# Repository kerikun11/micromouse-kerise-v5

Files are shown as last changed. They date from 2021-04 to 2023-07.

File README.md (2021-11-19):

# MicroMouse KERISE v5

ハーフサイズマイクロマウス

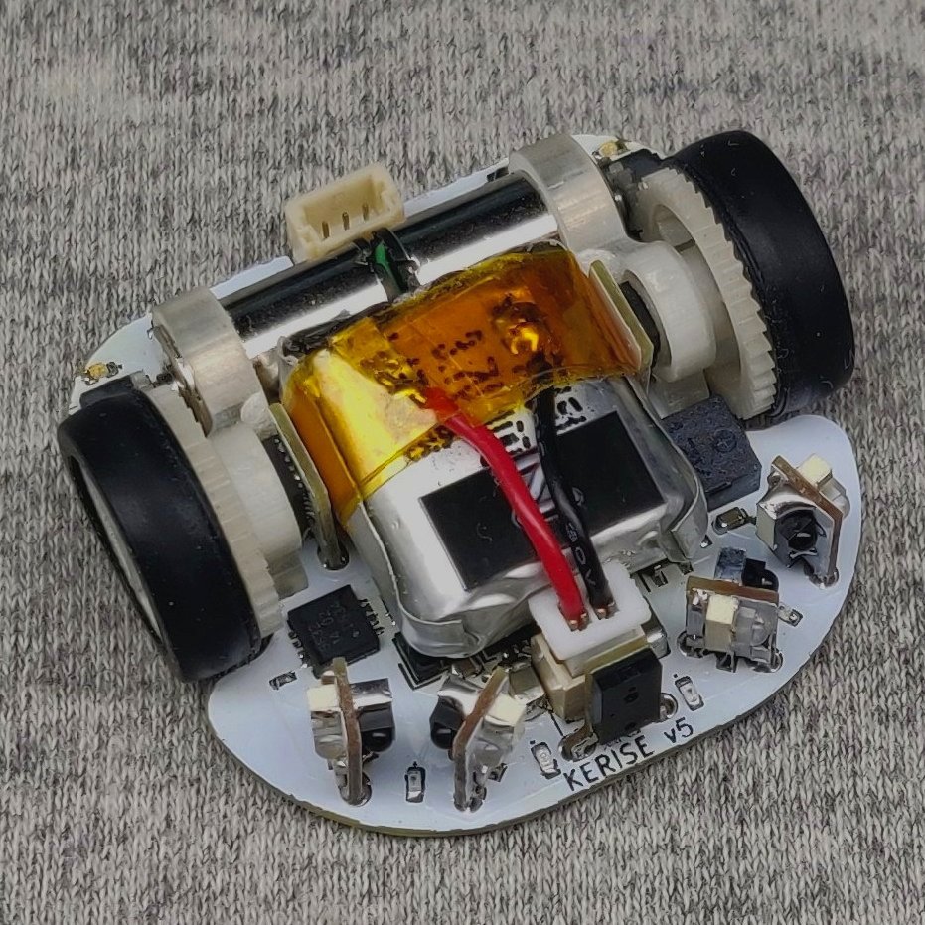
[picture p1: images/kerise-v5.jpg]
KERISE v5


## 戦績

なし

## スペック

| 部品 | 型番 | 備考 |
| :--- | :--- | :--- |
| モーター | 不明 | 直径6mm 長さ10mm コアレスモーター |
| エンコーダ | MA730 | 4096パルス 磁気式 |
| マイコン | ESP32-PICO-D4 | 240MHz dual core |
| 赤外線LED | SFH4045N | 波長940mm |
| フォトトランジスタ | SFH3015FA | 波長940nm |
| モータードライバ | DRV8835 | 最大電流1.5A x 2ch |
| 6軸センサ | ICM-20602 | 3軸ジャイロ+3軸加速度 |
| バッテリー | 不明 | 3.7V 25C 100mAh 1S |

## 回路設計

- KiCad

## 機体設計

- Fusion 360

## 開発環境

- PlatformIO Espressif32 Arduino

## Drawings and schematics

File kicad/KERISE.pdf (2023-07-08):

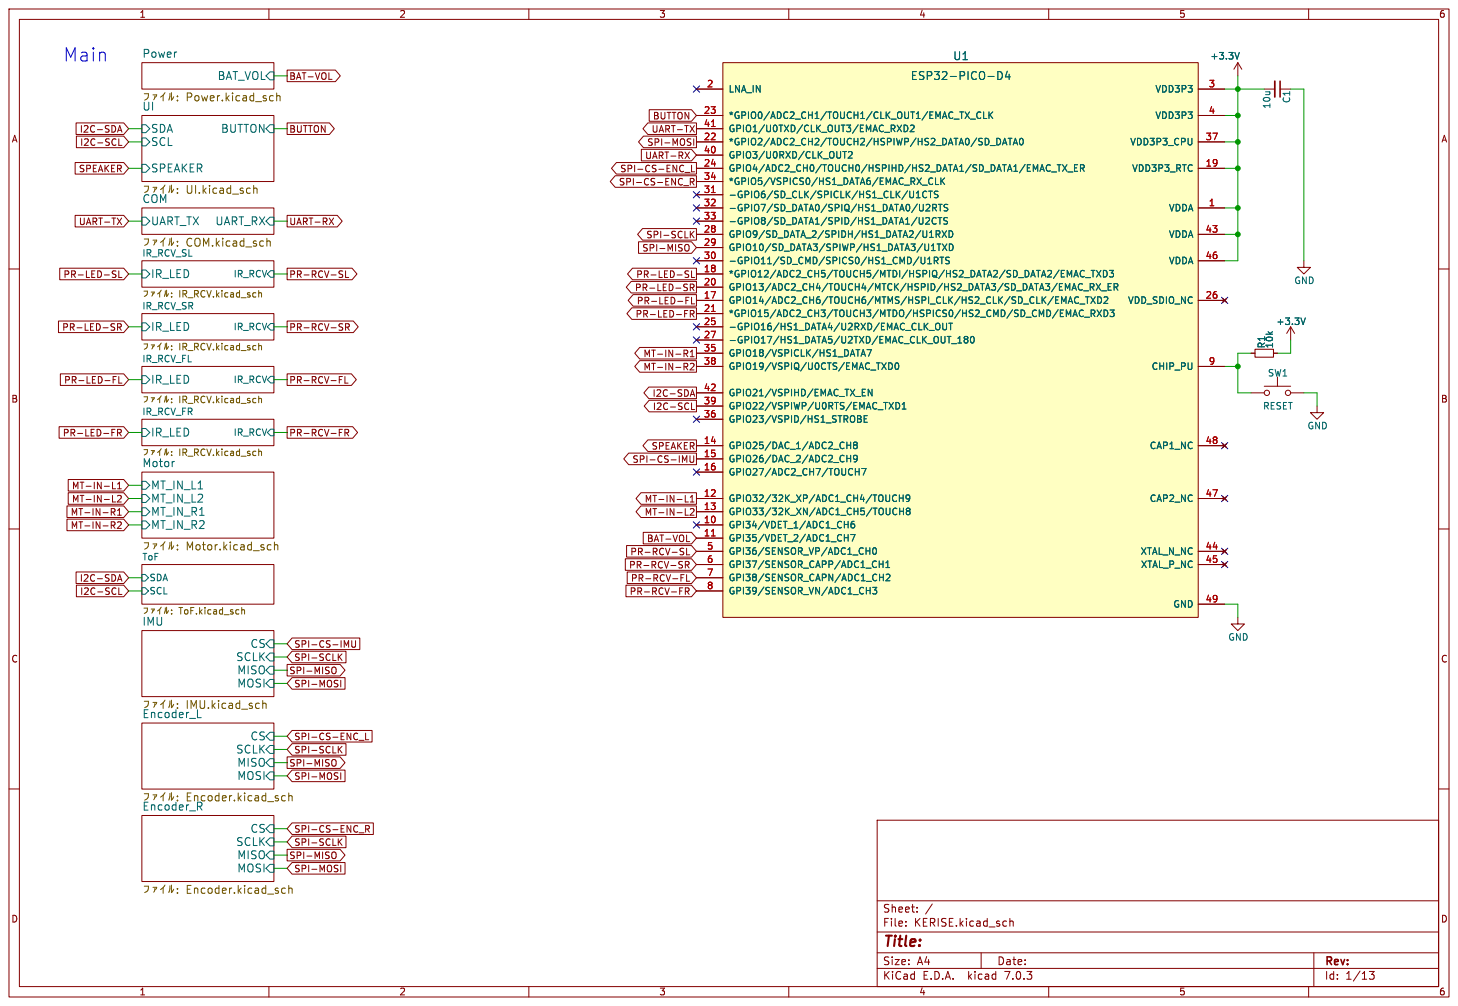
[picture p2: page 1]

BUTTON
PR-RCV-FL UART-RX

SPI-CS-ENC_L BUTTON
SPI-MOSI UART-TX

*GPIO2/ADC2_CH2/TOUCH2/HSPIWP/HS2_DATA0/SD_DATA0 22
I2C-SCL PR-LED-SL SPI-SCLK
SPI-MISO

PR-LED-FL PR-LED-SR

I2C-SDA MT-IN-R1 MT-IN-R2

SPI-MOSI SPI-CS-ENC_R

Id: 1/13 Title: File: KERISE.kicad_sch Sheet: /

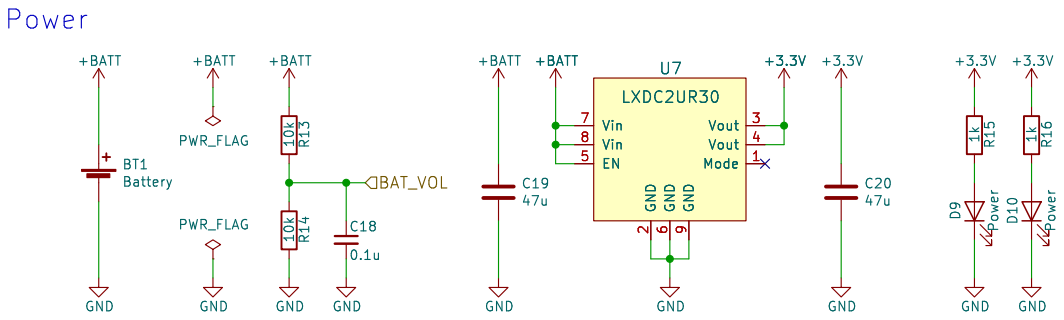
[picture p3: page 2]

2 Vout 3 Vout 4 EN 5 GND

Id: 2/13 Title: File: Power.kicad_sch Sheet: /Power/ C20

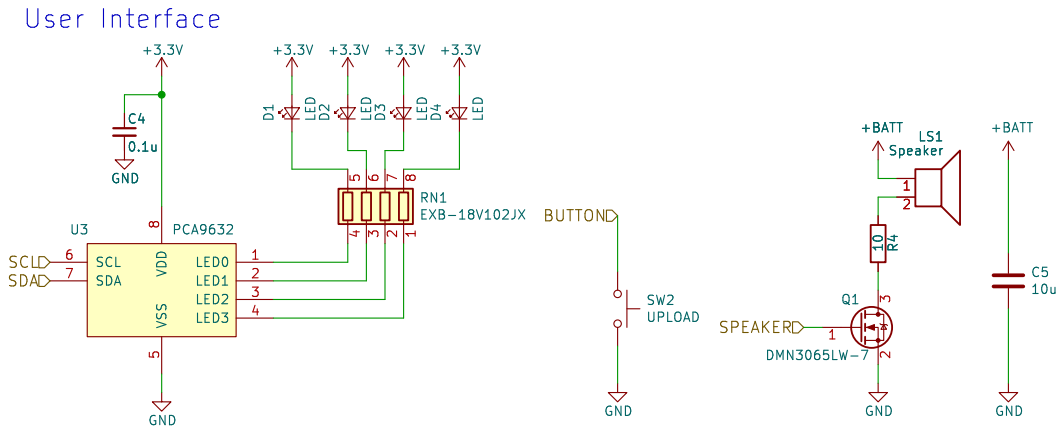
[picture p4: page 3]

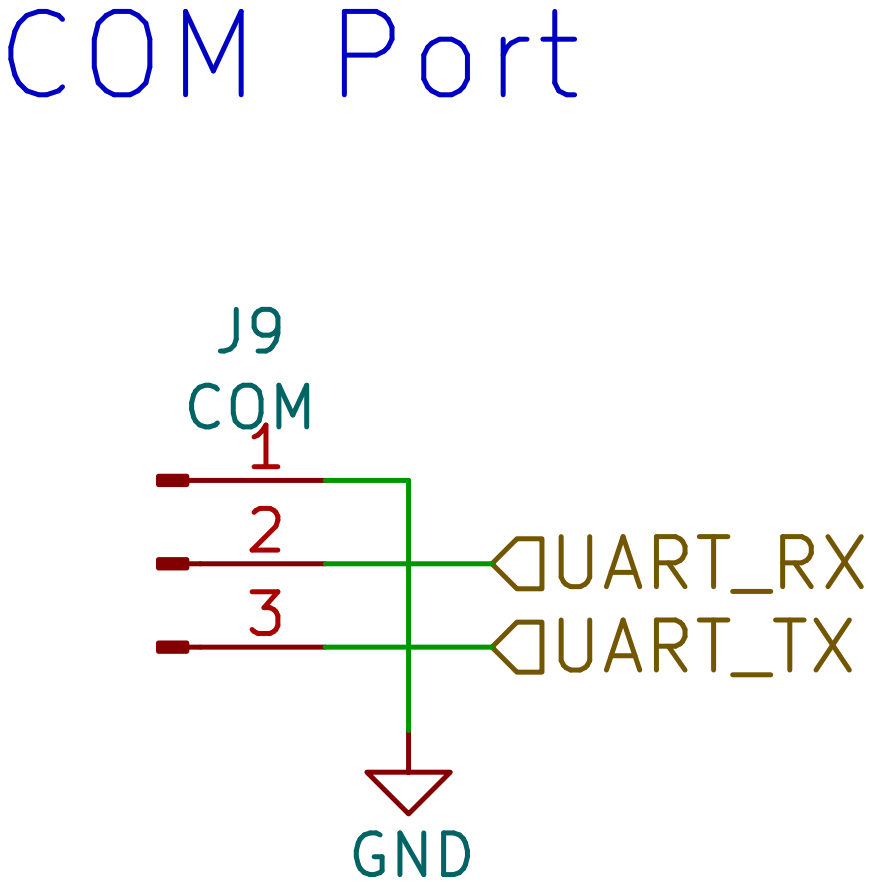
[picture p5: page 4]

Id: 4/13 Title: File: COM.kicad_sch Sheet: /COM/ GND

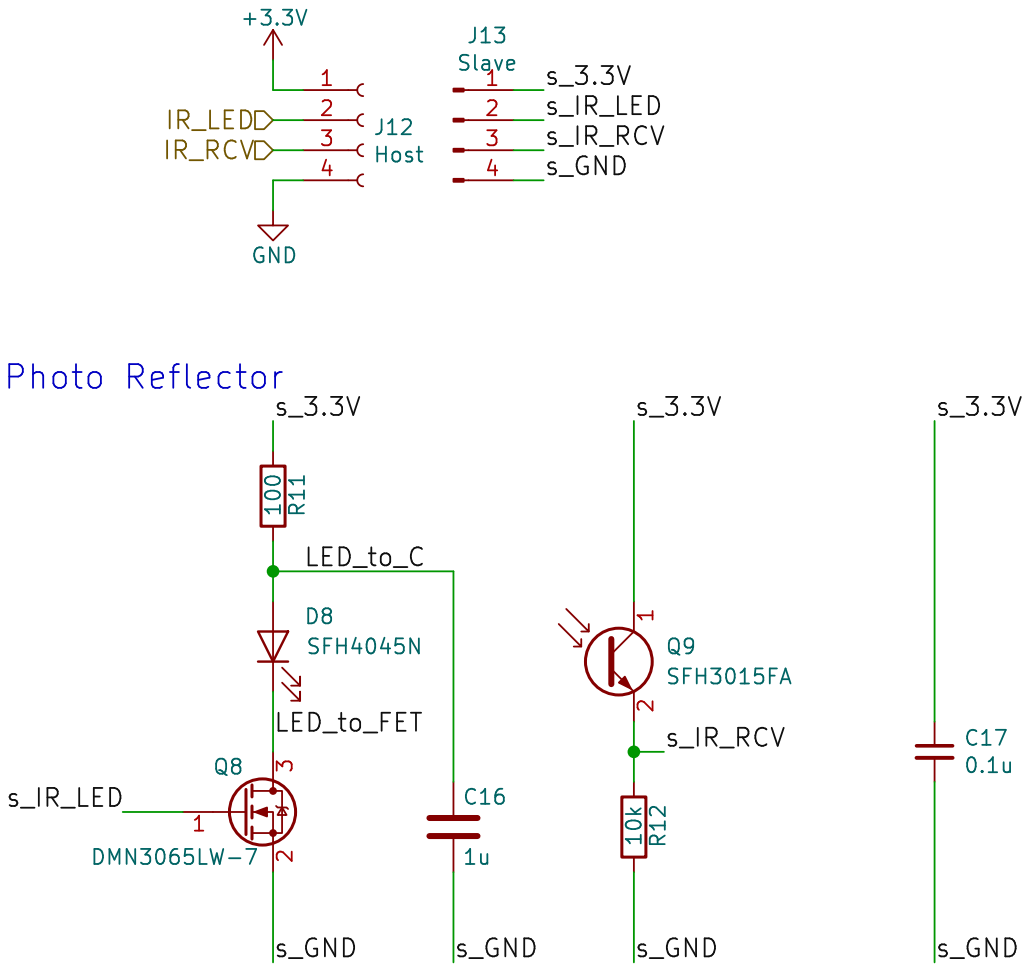
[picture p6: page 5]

Id: 5/13 Title: File: IR_RCV.kicad_sch Sheet: /IR_RCV_SL/ C17

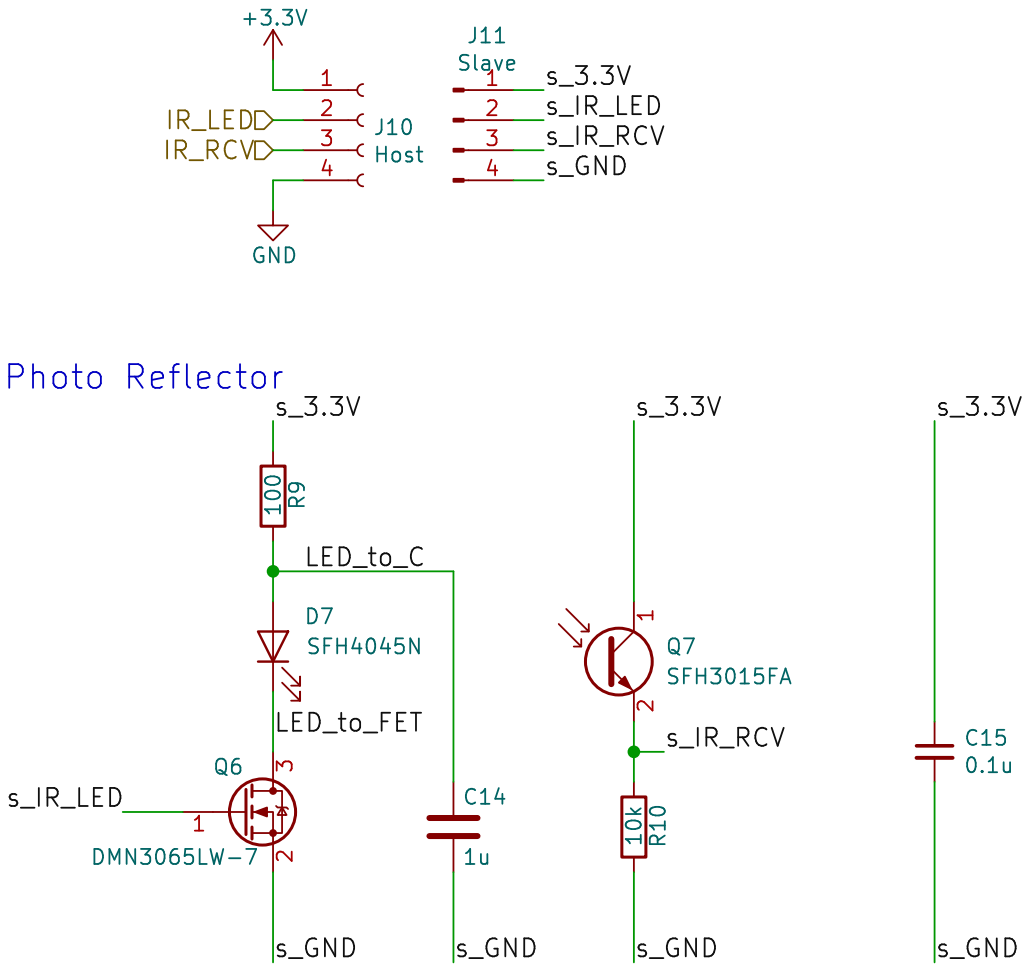
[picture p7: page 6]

Id: 6/13 Title: File: IR_RCV.kicad_sch Sheet: /IR_RCV_SR/ C15

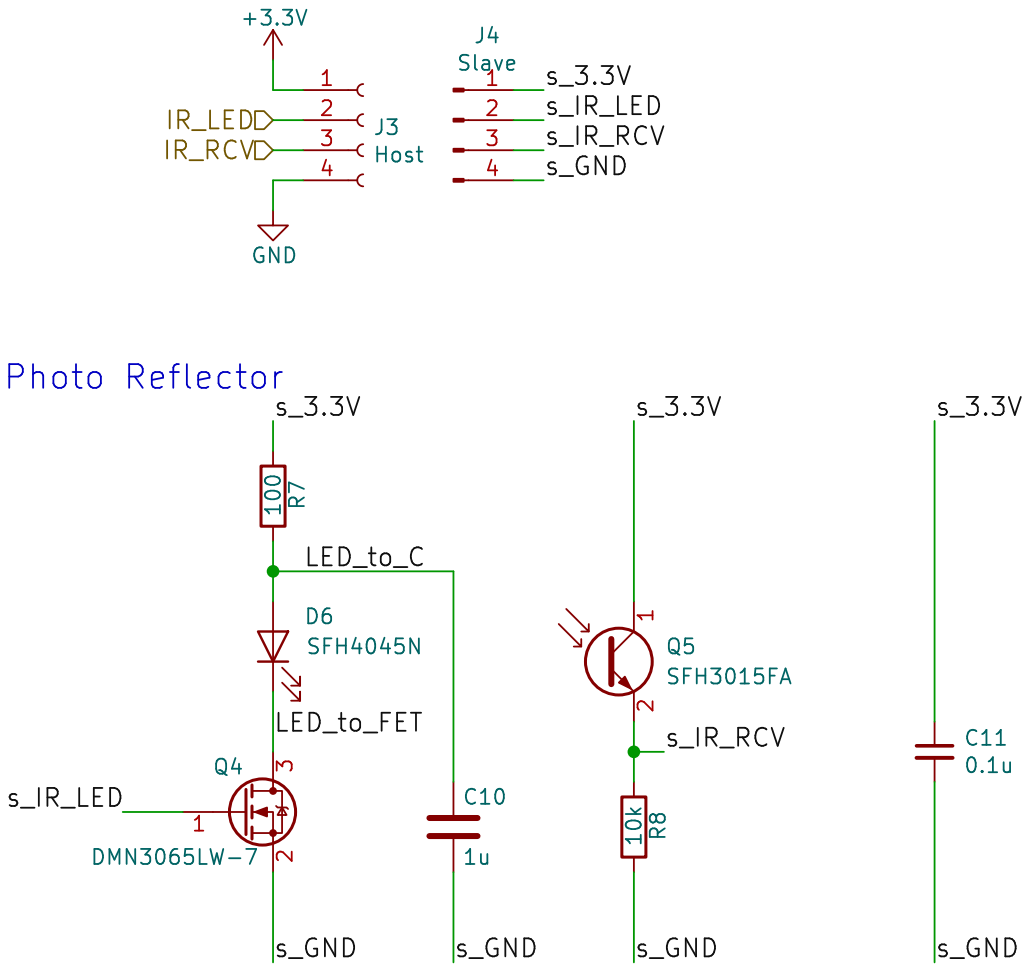
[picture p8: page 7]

Id: 7/13 Title: File: IR_RCV.kicad_sch Sheet: /IR_RCV_FL/ C11

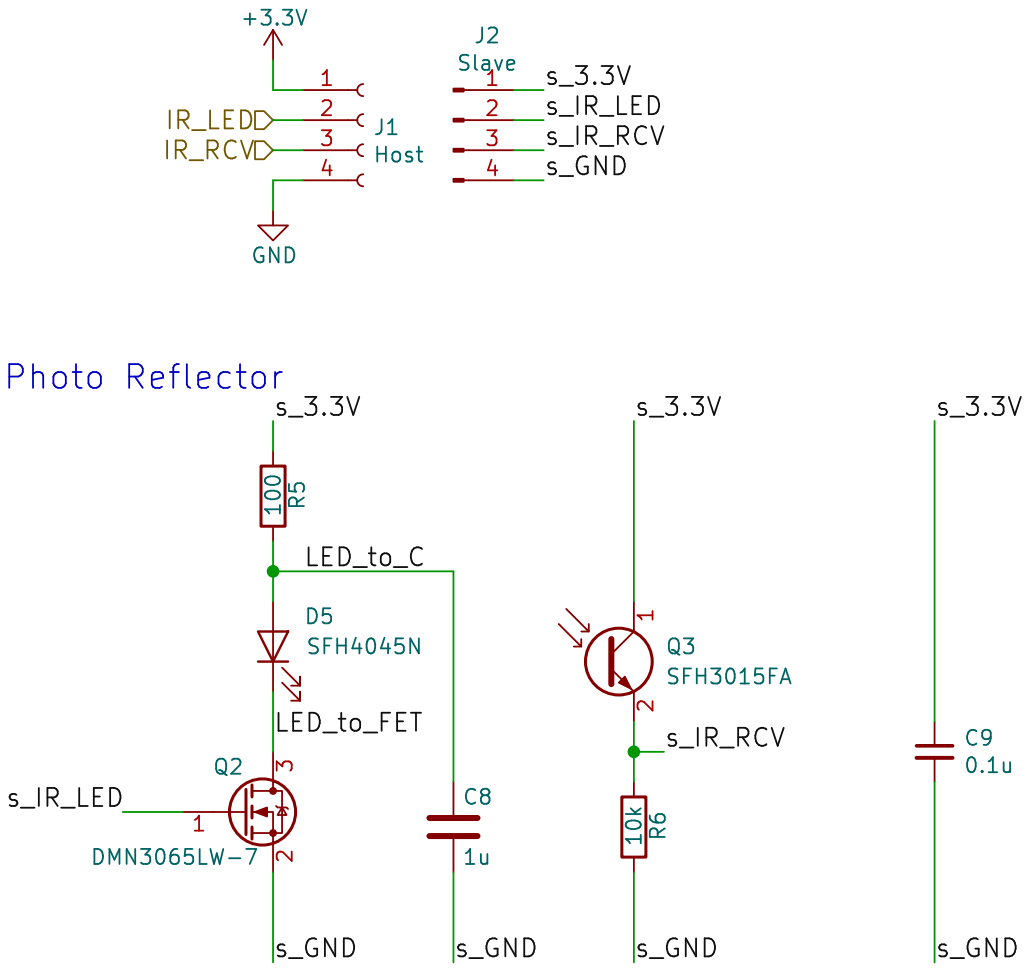
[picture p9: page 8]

Id: 8/13 Title: File: IR_RCV.kicad_sch Sheet: /IR_RCV_FR/ C9

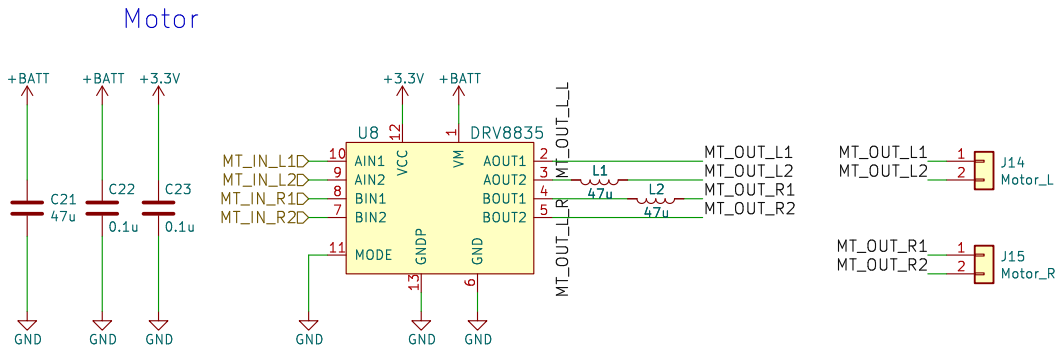
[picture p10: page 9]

1 AIN1 10 MODE 11 VCC 12 GNDP 13 AOUT1 2 AOUT2 3 BOUT1 4 BOUT2 5 GND

Id: 9/13 Title: File: Motor.kicad_sch Sheet: /Motor/

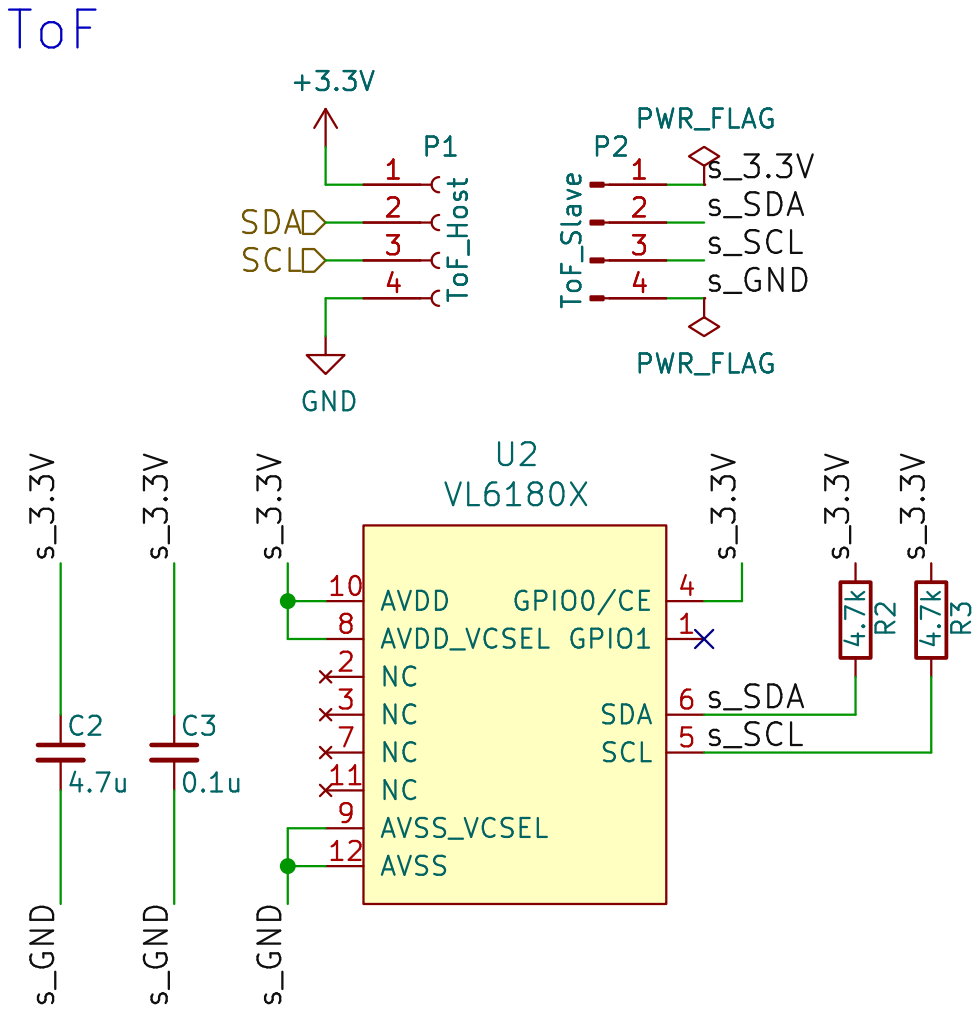
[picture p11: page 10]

Id: 10/13 Title: File: ToF.kicad_sch Sheet: /ToF/ C2

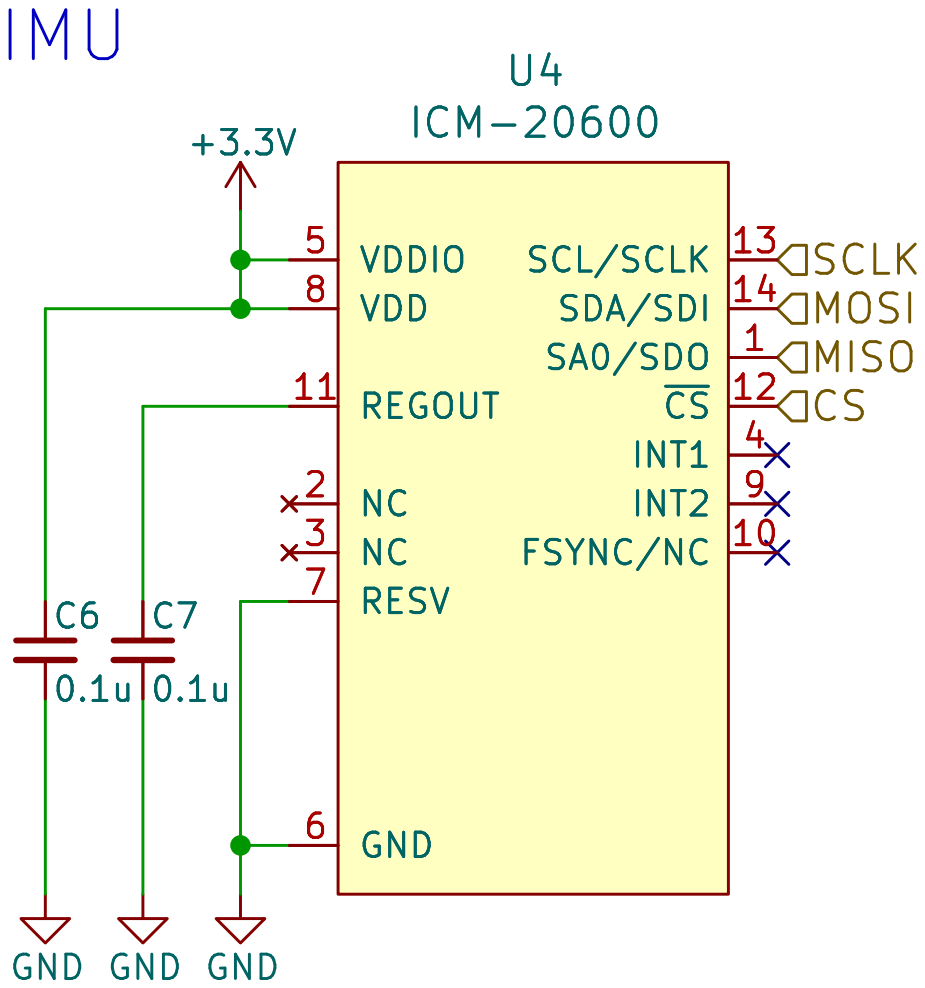
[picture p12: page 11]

Id: 11/13 Title: File: IMU.kicad_sch Sheet: /IMU/

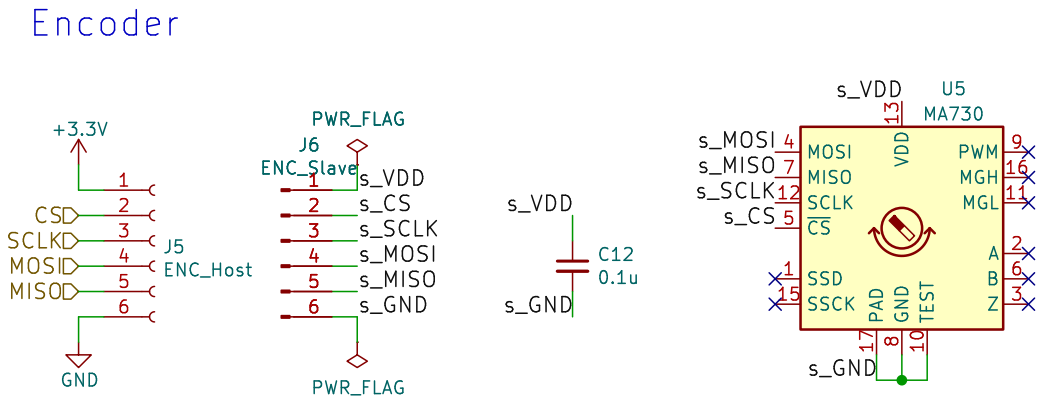
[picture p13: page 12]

Id: 12/13 Title: File: Encoder.kicad_sch Sheet: /Encoder_L/


Id: 13/13 Title: File: Encoder.kicad_sch Sheet: /Encoder_R/

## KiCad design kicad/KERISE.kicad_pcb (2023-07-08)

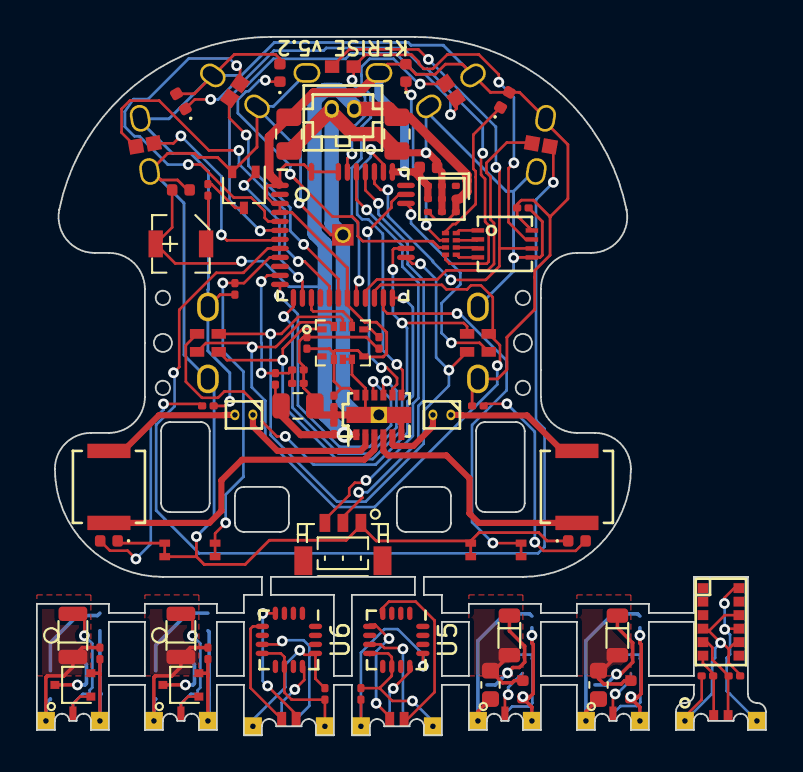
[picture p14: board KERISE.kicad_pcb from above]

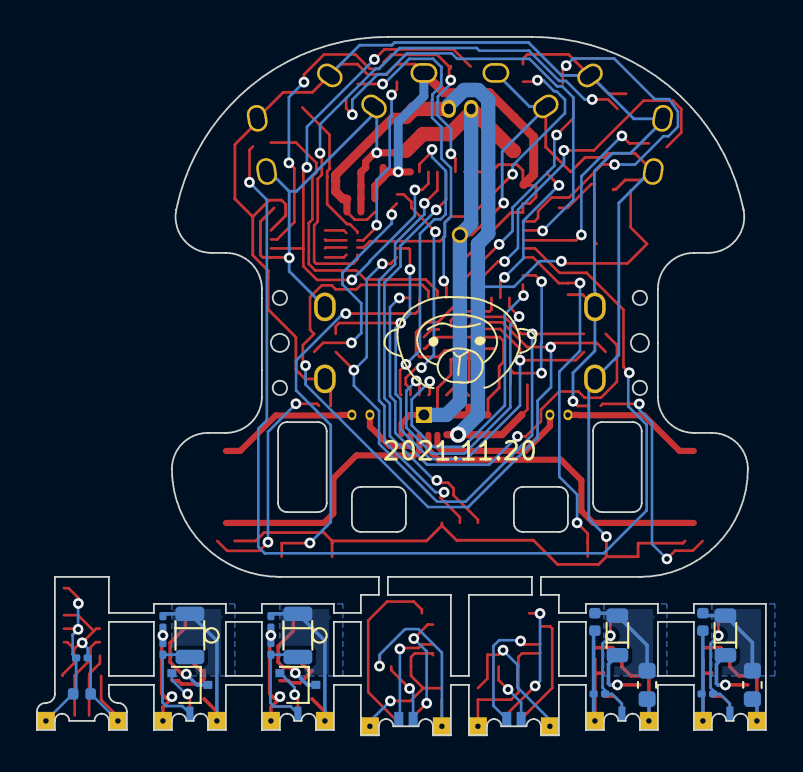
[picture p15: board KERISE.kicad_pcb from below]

Board: 2 copper layers, 40.5 x 38.8 mm, 90 parts (18 on the bottom side), 88 nets.

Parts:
BT1: Battery; Hirose_DF13-02P-1.25DSA_02x1.25mm_Straight
C1, C5: 10u; C_0402_1005Metric
C2: 4.7u; C_0402_1005Metric
C3, C4, C6, C7, C9, C11, C12, C13, C15, C17, C18, C22, C23: 0.1u; C_0201_0603Metric
C8, C10, C14, C16: 1u; C_0402_1005Metric
C19, C20, C21: 47u; C_0805_2012Metric
D1, D2, D3, D4: LED; LED_0402_1005Metric
D5, D6, D7, D8: SFH4045N; SFH4045N_L
D9, D10: Power; LED_0402_1005Metric
J1, J3, J10, J12: Host; IR_HOST_V_04
J2, J4, J11, J13: Slave; IR_SLAVE_V_04
J5, J7: ENC_Host; STAND_HOST_06
J6, J8: ENC_Slave; STAND_SLAVE_06
J9: COM; JST_SH_BM03B-SRSS-TB_03x1.00mm_Straight
J14: Motor_L; SMD_conn_2
J15: Motor_R; SMD_conn_2
L1, L2: 47u; L_4018
LS1: Speaker; SMT-0340-T-R
P1: ToF_Host; STAND_HOST_04
P2: ToF_Slave; STAND_SLAVE_04
Q1, Q2, Q4, Q6, Q8: DMN3065LW-7; SOT-323_SC-70
Q3, Q5, Q7, Q9: SFH3015FA; SFH3015FA_L
R1, R6, R8, R10, R12, R13, R14: 10k; R_0201_0603Metric
R2, R3: 4.7k; R_0201_0603Metric
R4: 10; R_0201_0603Metric
R5, R7, R9, R11: 100; R_0603_1608Metric
R15, R16: 1k; R_0201_0603Metric
RN1: EXB-18V102JX; R_Array_Concave_4x0201
SW1: RESET; EVPBB
SW2: UPLOAD; EVPBB
U1: ESP32-PICO-D4
U2: VL6180X
U3: PCA9632; DFN-8-1EP_3x3mm_Pitch0.5mm
U4: ICM-20600
U5, U6: MA730
U7: LXDC2UR30; LXDC2UR
U8: DRV8835

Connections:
+3V3: C1.2, C4.1, C6.1, C20.1, C23.1, D1.2, D2.2, D3.2, D4.2, J1.1, J3.1, J5.1, J7.1, J10.1, J12.1, P1.1, R1.2, R15.1, R16.1, U1.1, U1.3, U1.4, U1.19, U1.37, U1.43, U1.46, U3.8, U4.5, U4.8, U7.3, U7.4, U8.12
+BATT: BT1.1, C5.1, C19.1, C21.1, C22.1, LS1.1, R13.1, U7.5, U7.7, U7.8, U8.1
/Encoder_L/s_CS: J6.2, U5.5
/Encoder_L/s_GND: C12.2, J6.6, U5.8, U5.10
/Encoder_L/s_MISO: J6.5, U5.7
/Encoder_L/s_MOSI: J6.4, U5.4
/Encoder_L/s_SCLK: J6.3, U5.12
/Encoder_L/s_VDD: C12.1, J6.1, U5.13
/Encoder_R/s_CS: J8.2, U6.5
/Encoder_R/s_GND: C13.2, J8.6, U6.8, U6.10
/Encoder_R/s_MISO: J8.5, U6.7
/Encoder_R/s_MOSI: J8.4, U6.4
/Encoder_R/s_SCLK: J8.3, U6.12
/Encoder_R/s_VDD: C13.1, J8.1, U6.13
/IR_RCV_FL/LED_to_C: C10.1, D6.2, R7.2
/IR_RCV_FL/LED_to_FET: D6.1, Q4.3
/IR_RCV_FL/s_3.3V: C11.1, J4.1, Q5.1, R7.1
/IR_RCV_FL/s_GND: C10.2, C11.2, J4.4, Q4.2, R8.2
/IR_RCV_FL/s_IR_LED: J4.2, Q4.1
/IR_RCV_FL/s_IR_RCV: J4.3, Q5.2, R8.1
/IR_RCV_FR/LED_to_C: C8.1, D5.2, R5.2
/IR_RCV_FR/LED_to_FET: D5.1, Q2.3
/IR_RCV_FR/s_3.3V: C9.1, J2.1, Q3.1, R5.1
/IR_RCV_FR/s_GND: C8.2, C9.2, J2.4, Q2.2, R6.2
/IR_RCV_FR/s_IR_LED: J2.2, Q2.1
/IR_RCV_FR/s_IR_RCV: J2.3, Q3.2, R6.1
/IR_RCV_SL/LED_to_C: C16.1, D8.2, R11.2
/IR_RCV_SL/LED_to_FET: D8.1, Q8.3
/IR_RCV_SL/s_3.3V: C17.1, J13.1, Q9.1, R11.1
/IR_RCV_SL/s_GND: C16.2, C17.2, J13.4, Q8.2, R12.2
/IR_RCV_SL/s_IR_LED: J13.2, Q8.1
/IR_RCV_SL/s_IR_RCV: J13.3, Q9.2, R12.1
/IR_RCV_SR/LED_to_C: C14.1, D7.2, R9.2
/IR_RCV_SR/LED_to_FET: D7.1, Q6.3
/IR_RCV_SR/s_3.3V: C15.1, J11.1, Q7.1, R9.1
/IR_RCV_SR/s_GND: C14.2, C15.2, J11.4, Q6.2, R10.2
/IR_RCV_SR/s_IR_LED: J11.2, Q6.1
/IR_RCV_SR/s_IR_RCV: J11.3, Q7.2, R10.1
/Motor/MT_OUT_L1: J14.1, U8.2
/Motor/MT_OUT_L2: J14.2, L1.1
/Motor/MT_OUT_L_L: L1.2, U8.3
/Motor/MT_OUT_L_R: L2.2, U8.4
/Motor/MT_OUT_R1: J15.1, L2.1
/Motor/MT_OUT_R2: J15.2, U8.5
/ToF/s_3.3V: C2.1, C3.1, P2.1, R2.1, R3.1, U2.4, U2.8, U2.10
/ToF/s_GND: C2.2, C3.2, P2.4, U2.9, U2.12
/ToF/s_SCL: P2.3, R3.2, U2.5
/ToF/s_SDA: P2.2, R2.2, U2.6
BAT-VOL: C18.1, R13.2, R14.1, U1.11
BUTTON: SW2.1, U1.23
GND: BT1.2, C1.1, C4.2, C5.2, C6.2, C7.2, C18.2, C19.2, C20.2, C21.2, C22.2, C23.2, D9.1, D10.1, J1.4, J3.4, J5.6, J7.6, J9.1, J10.4, J12.4, P1.4, Q1.2, R14.2, SW1.2, SW2.2, U1.49, U3.5, U4.6, U4.7, U7.2, U7.6, U7.9, U8.6, U8.11, U8.13
I2C-SCL: P1.3, U1.39, U3.6
I2C-SDA: P1.2, U1.42, U3.7
MT-IN-L1: U1.12, U8.10
MT-IN-L2: U1.13, U8.9
MT-IN-R1: U1.35, U8.8
MT-IN-R2: U1.38, U8.7
unnamed: C7.1, U4.11
unnamed: D1.1, RN1.5
unnamed: D2.1, RN1.6
unnamed: D3.1, RN1.7
unnamed: D4.1, RN1.8
unnamed: D9.2, R15.2
unnamed: D10.2, R16.2
unnamed: LS1.2, R4.1
unnamed: Q1.3, R4.2
unnamed: R1.1, SW1.1, U1.9
unnamed: RN1.1, U3.4
unnamed: RN1.2, U3.3
unnamed: RN1.3, U3.2
unnamed: RN1.4, U3.1
PR-LED-FL: J3.2, U1.17
PR-LED-FR: J1.2, U1.21
PR-LED-SL: J12.2, U1.18
PR-LED-SR: J10.2, U1.20
PR-RCV-FL: J3.3, U1.7
PR-RCV-FR: J1.3, U1.8
PR-RCV-SL: J12.3, U1.5
PR-RCV-SR: J10.3, U1.6
SPEAKER: Q1.1, U1.14
SPI-CS-ENC_L: J5.2, U1.24
SPI-CS-ENC_R: J7.2, U1.34
SPI-CS-IMU: U1.15, U4.12
SPI-MISO: J5.5, J7.5, U1.29, U4.1
SPI-MOSI: J5.4, J7.4, U1.22, U4.14
SPI-SCLK: J5.3, J7.3, U1.28, U4.13
UART-RX: J9.2, U1.40
UART-TX: J9.3, U1.41

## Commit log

2017-12-04 KiCad設計中のファイルを追加
    ESP32-PICO-D4版
    [AXIS_SENSOR.sch, COM.sch, Encoder.sch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]
2017-12-06 自動配線成功
    [KERISE.dsn, KERISE.kicad_pcb, KERISE.sch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]
2017-12-06 バッテリーコネクタの位置を改良
    電池に干渉しないように．
    自動配線成功済
    [KERISE.dsn, KERISE.kicad_pcb]
2017-12-10 基板発注
    KERISEv5初版はこのデータで発注済
    [KERISE.kicad_pcb]
2018-01-04 回路を改良
    受光部をフォトトランジスタに変更
    測距センサをVL6180Xに変更
    動作電圧を3Vに変更
    [AXIS_SENSOR.sch, COM.sch, Encoder.sch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]
2018-01-05 電源ラインを配線
    あとは自動配線
    [KERISE.dsn, KERISE.kicad_pcb, KERISE.sch]
2018-01-08 7本残して自動配線終了
    [KERISE.dsn, KERISE.kicad_pcb, KERISE.sch]
2018-01-08 電源回りの配線を改良
    [KERISE.dsn, KERISE.kicad_pcb]
2018-01-08 自動配線を適用，LOGOを貼り付け
    [KERISE.kicad_pcb]
2018-04-09 部品を配置
    [AXIS_SENSOR.sch, COM.sch, Charger.sch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]
2018-04-30 自動配線を適用
    [KERISE.kicad_pcb]
2018-05-13 回路図を改良
    [IR_RCV.sch]
2020-05-10 回路を編集 ToFを除去
    [AXIS_SENSOR.sch, COM.sch, Encoder.sch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]
2020-05-10 部品を配置 kicad5
    [AXIS_SENSOR.sch, COM.sch, Charger.sch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]
2020-05-10 回路にMA702を追加
    [Encoder.sch, IMU.sch, KERISE.dsn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]
2020-05-10 エンコーダ基板を調整，配線可能に
    [KERISE.dsn]
2020-05-10 自動配線あと4本
    [IMU.sch, KERISE.dsn, KERISE.kicad_pcb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]
2020-05-10 自動配線4本Take2
    [KERISE.dsn, KERISE.kicad_pcb]
2020-05-10 手動配線
    [KERISE.kicad_pcb]
2020-05-10 コンデンサを追加
    [COM.sch, Encoder.sch, Fan.sch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]
2020-05-10 配線を修正
    - エンコーダの配線が基板外に出てた（Elecrowから指摘）
    [KERISE.kicad_pcb]
2020-05-10 回路図のPDFを追加
2020-05-10 KERISEv5に向けて回路図を更新
    [COM.sch, Encoder.sch, Fan.sch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]
2020-05-10 フットプリントを割り当て
    [COM.sch, Encoder.sch, Fan.sch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]
2020-05-10 配置を改良
    [KERISE.dsn, KERISE.kicad_pcb]
2020-05-10 リファレンスを除去
    [IR_RCV.sch, KERISE.kicad_pcb, Power.sch]
2020-05-10 フットプリントを改良
    [Encoder.sch, Fan.sch, IMU.sch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]
2020-05-10 自動配線結果
2020-05-10 アンテナを外側に配置
    [IMU.sch, KERISE.dsn, KERISE.kicad_pcb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]
2020-05-10 デザインルールを緩和
    [KERISE.dsn, KERISE.kicad_pcb]
2020-05-10 3Dシェイプを割り当て
    [KERISE.dsn, KERISE.kicad_pcb]
2020-05-10 以前成功した自動配線を適用，基板発注
    [KERISE.dsn, KERISE.kicad_pcb]
2020-05-10 LEDの抵抗を集合抵抗に変更
    [IMU.sch, IR_RCV.sch, KERISE.dsn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]
2020-05-10 配線を改良
    [KERISE.dsn, KERISE.kicad_pcb]
2020-05-10 回路図の警告を除去
    [KERISE.dsn, KERISE.kicad_pcb]
2020-05-10 自動配線を適用，基板発注
    [KERISE.kicad_pcb]
2020-05-10 matlabディレクトリを整理
2020-05-10 kicad に .gitignore を導入
2020-05-10 未配線あり
    [KERISE.dsn, KERISE.kicad_pcb]
2020-05-10 配線幅を改良
    [Encoder.sch, IMU.sch, IR_RCV.sch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]
2020-05-10 エンコーダー基板の位置を調整
    [KERISE.dsn, KERISE.kicad_pcb, Motor.sch]
2020-05-10 fix pcb margin
    [KERISE.kicad_pcb]
2020-05-10 回路を修正，未配線
    [KERISE.dsn, KERISE.kicad_pcb]
2020-05-10 update kicad .gitignore
    [IMU.sch, IR_RCV.sch, Motor.sch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]
2020-05-10 予備配線完了
    [COM.sch, Encoder.sch, IMU.sch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]
2020-05-10 自動配線完了
    [KERISE.dsn, KERISE.kicad_pcb]
2021-11-20 KiCad: update pcb
    [COM.sch, Encoder.sch, IMU.sch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]
2021-12-27 generate sketch PDF
    [KERISE.kicad_pcb]
2023-07-08 update to kicad 7
    [COM.kicad_sch, COM.sch, Encoder.kicad_sch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]
